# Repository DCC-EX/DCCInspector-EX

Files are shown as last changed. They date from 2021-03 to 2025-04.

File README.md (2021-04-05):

# DccInspector-EX

## Summary

Diagnostic/sniffer program for DCC analysis, based on an Arduino or ESP32 target.
The bit structure and packet structure are analysed and reported, and packets are decoded
and displayed in binary and also in a textual form.

On Arduino, the program produces output to the Serial port.  

On ESP32, it supports HTTP output via WiFi, and will display a reduced set of information
on an OLED display.  A button can be configured to allow the screen to be scrolled to display 
more information.  Development boards such as the Heltec Kit 32 include OLED and a button and
can be used directly.  The ESP32 will go into deep sleep mode (to preserve battery when used stand-alone) if no input 
DCC signal is detected for two minutes, it resumes when reset.

## Hardware Interface

The device may be directly connected to a DCC controller of the same I/O voltage and earth, e.g. in a
DCC++ or DCC++ EX system.  If it is used to monitor DCC signals, which are
normally bipolar 12-18V signals, an optocoupler circuit will be required.

Various circuits are discussed on the internet, but if you use a 6N137 optocoupler I 
would recommend a 1nF capacitor across the optocoupler input to stabilise the DCC input signal.  
Without this the opto-isolator may experience ringing, causing fleeting interrupts on the input 
(recorded as 'glitches' in the diagnostics).

I use a pull-up resistor of 470 ohms (labelled R3 below) on the output pin 6, connected to 5V; 
a larger resistor (even the Arduino's internal pull-up) will generally still work but may slow 
down the optocoupler.  Using the internal pull-up (~25Kohm), the rise-time on the signal is some microseconds 
in length, compared to around 200ns with a 470 (or 330) ohm pull-up.  This may be acceptable in a decoder where the
timing requirements may be relaxed, but a faster response is preferred for a diagnostic tool.

No connection is necessary to pin 7, although some versions of the circuit show a pull-up resistor here.

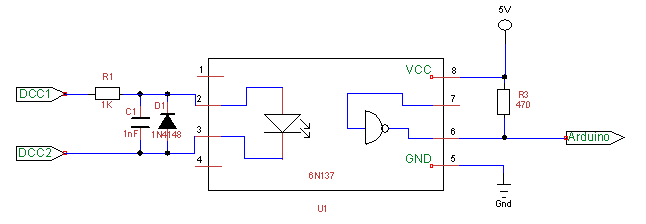
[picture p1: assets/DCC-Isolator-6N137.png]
Recommended Optocoupler Circuit


Strictly, the 6N137 isn't rated for the 3.3V supply used on an ESP8266 or ESP32.
I've had good results running with the circuit shown above with a 3.3V supply (replacing R3 with 330 ohm), 
but if you want to do things properly, the VCC terminal of the 6N137 should be
connected to +5V, or the optocoupler should be replaced with a 3.3V tolerant optocoupler.  In either case,
R3 should be connected to +3.3V to avoid putting too high a voltage on the ESP's input pin.

The default input pin used by the sketch depends on the target used.  For Arduino Uno and Nano, pin 8; 
for Mega, pin 49.  For the ESP8266/ESP32 it's GPIO2 (labelled D4 on the 8266 NodeMCU).

## Target Platforms

The diagnostic program supports the Arduino Uno, Nano, Mega and ESP32 particularly.

On Arduino, measurements are performed at an accuracy of 1/2 or 1/16th microsecond using Timer1 input 
capture mode, and calculation results are rounded to 1 microsecond.  

For increased compatibility with other microcontrollers, it is possible to use the micros() function for timing.
However, on an Arduino Uno/Nano/Mega this introduces up to 3us error in the micros() result, plus up to
6.5us uncertainty in the scheduling of the interrupt which samples the micros() value; consequently, the 
measured pulse length will, approximately once every millisecond, be off by up to 10us, and the rest of 
the time be up to 3us out.  This mode of operation is not recommended.

The sketch also supports the ESP8266 and ESP32.
On the ESP8266, the timing is performed using the micros() function.  Consequently, 
some inaccuracies due to interrupts are still present, of the order of 4us either way.  

The ESP32 runs in input capture mode, which works very well and potentially can support a 
measurement accuracy of around 4ns.  The sketch uses the default 12.5ns timer resolution and rounds 
the results to 1us accuracy.

## WiFi and Web Browser

On ESP8266 and ESP32, an HTTP server is provided which allows the output to be viewed from
a standard browser.  The first time the device starts, it will attempt to get WiFi credentials from the
router using WPS protocol.   Press the WPS button on the router before resetting the device, and
the device should connect to the router.  When the device is reset or started in future, it will 
connect using the same credentials by preference.

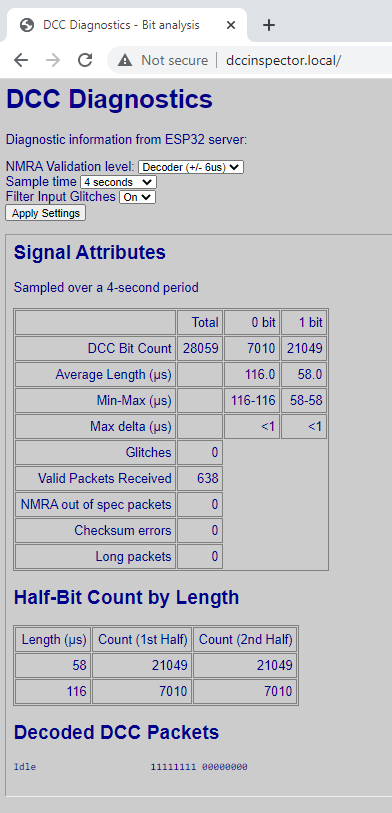
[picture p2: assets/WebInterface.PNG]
Example of output in web browser Example of web output


## Serial USB Output

The sketch produces output to the Serial stream, by default
once every 4 seconds.  The output statistics includes bit counts, 
bit lengths, checksum errors, packets too long, and 
time spent within the interrupt code.  Fleeting input state changes
(<= 3us) are optionally filtered and counted.  A break-down of pulse counts by 
length can also be produced, to monitor the consistency of the DCC signal.
The bit stream is validated against the specifications in NMRA S-9.1 (2020) for bit length 
and delta.  The validation can be selected through the serial monitor to be strict=0 (no validation), strict=1 
(NMRA Decoder compliance level) or strict=2 (NMRA Controller compliance level).  
The number of packets rejected due to non-compliance is recorded and displayed.

In between statistics output, received DCC packets are decoded and 
printed; duplicate throttle packets and idle packets are however not printed more than once per period.

Press '?' in the serial monitor to see help of the commands available.  The 
breakdown of pulse lengths is not displayed by default, press 'B' to enabled it.  
Likewise, the CPU statistics are not displayed by default, press 'C' to enable them.

## Example Output On Serial USB

### Example Uno Monitoring DCC++ EX 3.0.10 (5V, 6N137 Optocoupler, Main Track, Strict NMRA):
All DCC packets are within the NMRA specification
and the pulse lengths are always within 1us of the target lengths of 116us and 58us.

This demonstrates the improvements in pulse quality which were introduced in DCC++EX in 
version 3.0.5 when running on an ATmega2560 board with standard motor pins, compared to the pulse lengths
measured for the DCC++EX version 3.0.4 below.  It is achieved by using the Arduino's
hardware PWM capabilities to generate the pulse transitions; this is accurate to one clock cycle,
i.e. 1/16th of a microsecond, although the measurement accuracy is reduced slightly by the optocoupler circuit.

```
-
Bit Count/4 sec=25621 (Zeros=9134, Ones=16486), Glitches=0
Valid Packets=446, NMRA out of spec=0, Checksum Errors=0, Lost pkts=0, Long pkts=0
0 half-bit length (us): 115.9 (115-116) delta < 1
1 half-bit length (us): 57.9 (57-58) delta < 1
------ Half-bit count by length (us) -------
57	3218	0
58	13270	16490
115	2444	150
116	6690	8984
--------------------------------------------
--
Loc 3 Rev128 25         00000011 00111111 00011010
Loc 7979 Fwd128 122     11011111 00101011 00111111 11111011
-
```

### Example ESP32 Monitoring DCC++ EX 3.0.4 (5V, 6N137 Optocoupler, Main Track, Strict NMRA)
When the DCC signal is generated within interrupt handling code within the Command Station, the accuracy of 
the signal cannot be maintained to such a high accuracy.  Below, we can see that the pulse length varies over a range of around 14us.  
This would mean that some packets are outside of the NMRA specification and may be ignored by the loco decoder.
The analyser reports 81 packets as out of spec and 351 in-spec, i.e. around 20% are out of spec.  This is not 
normally a problem on a DCC layout as each packet is transmitted at least three times.  If one packet doesn't get 
through, the probability is that one of the retransmissions will!

The half-bit counts are turned off here, but CPU monitoring within the analyser is turned on.

```
-
Bit Count/4 sec=24865 (Zeros=10167, Ones=14697), Glitches=0
Valid Packets=351, NMRA out of spec=81, Checksum Errors=0, Lost pkts=0, Long pkts=0
0 half-bit length (us): 115.9 (109-122) delta < 14
1 half-bit length (us): 57.5 (51-64) delta < 14
IRC Duration (us): 2.2 (1-10),  CPU load: 27.5%
--
Loc 7552 Fwd128 33      11011101 10000000 00111111 10100010
Loc 3 Fwd128 25         00000011 00111111 10011010
-
```

### Example Uno Monitoring DCC++ Classic (5V direct connection, Main Track, Strict NMRA):
The original DCC++ Classic also uses the hardware PWM capabilities of the Arduino to generate the 
DCC pulse transitions.  This is capable of accuracy to within one clock cycle, as demonstrated in
the results below.

```
-
Bit Count/4 sec=27573 (Zeros=9881, Ones=17692), Glitches=0
Valid Packets=411, NMRA out of spec=0, Checksum Errors=0, Lost pkts=0, Long pkts=0
0 half-bit length (us): 100.0 (100-100) delta < 1
1 half-bit length (us): 58.0 (58-58) delta < 1
IRC Duration (us): 29.8 (27-39),  CPU load: 54.6%
------ Half-bit count by length (us) -------
58      17692   17692
100     9882    9882
--------------------------------------------
--
Loc 7801 Fwd128 55      11011110 01111001 00111111 10111000
Loc 2323 Fwd128 5       11001001 00010011 00111111 10000110
-
```

## Command Summary

Keyboard commands that can be sent via Serial Monitor:

```
 1 = 1s refresh time
 2 = 2s 
 3 = 4s (default)
 4 = 8s
 5 = 16s
 6 = 4 DCC packet buffer
 7 = 8
 8 = 16
 9 = 32 (default)
 0 = 64
 a = show accessory packets toggle
 l = show locomotive packets toggle
 d = show diagnostics toggle
 h = show heartbeat toggle
 b = show half-bit counts by length
 c = show cpu/irc usage in sniffer
 f = input filter toggle
 s = set NMRA compliance strictness (0=none,1=decoder,2=controller)
 ? = help (show this information)
```

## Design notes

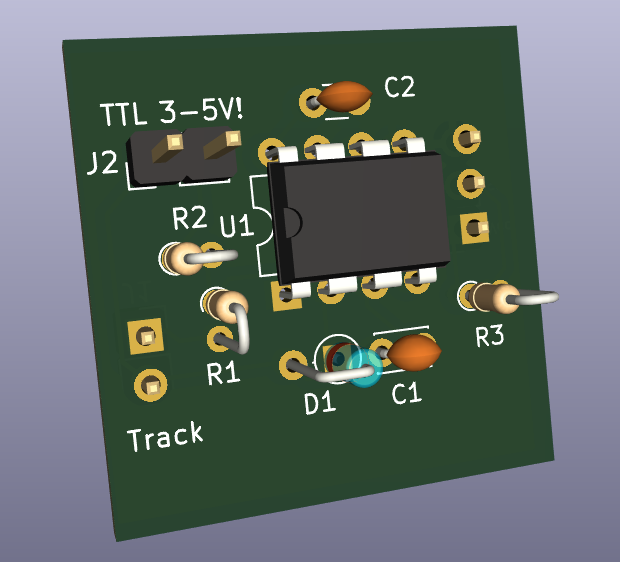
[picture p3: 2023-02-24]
hardware/optoiso-board-only/board_front.png

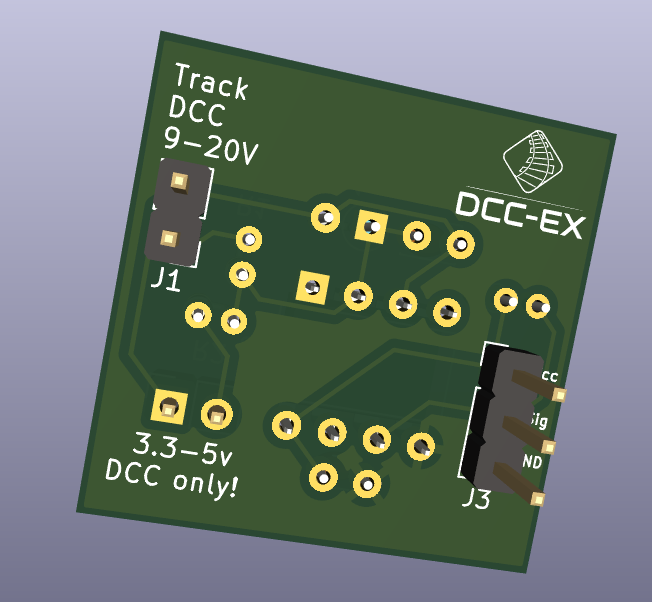
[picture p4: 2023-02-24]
hardware/optoiso-board-only/board_back.png

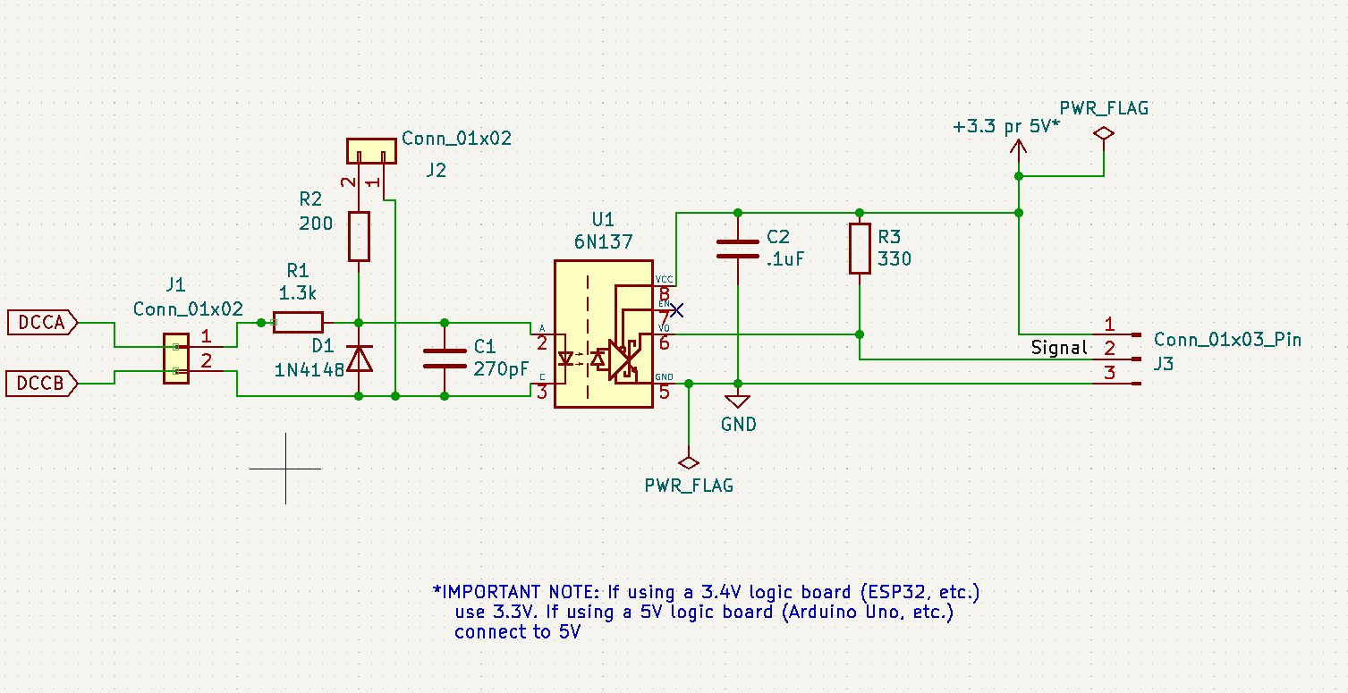
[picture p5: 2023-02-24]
hardware/optoiso-board-only/schematic.png

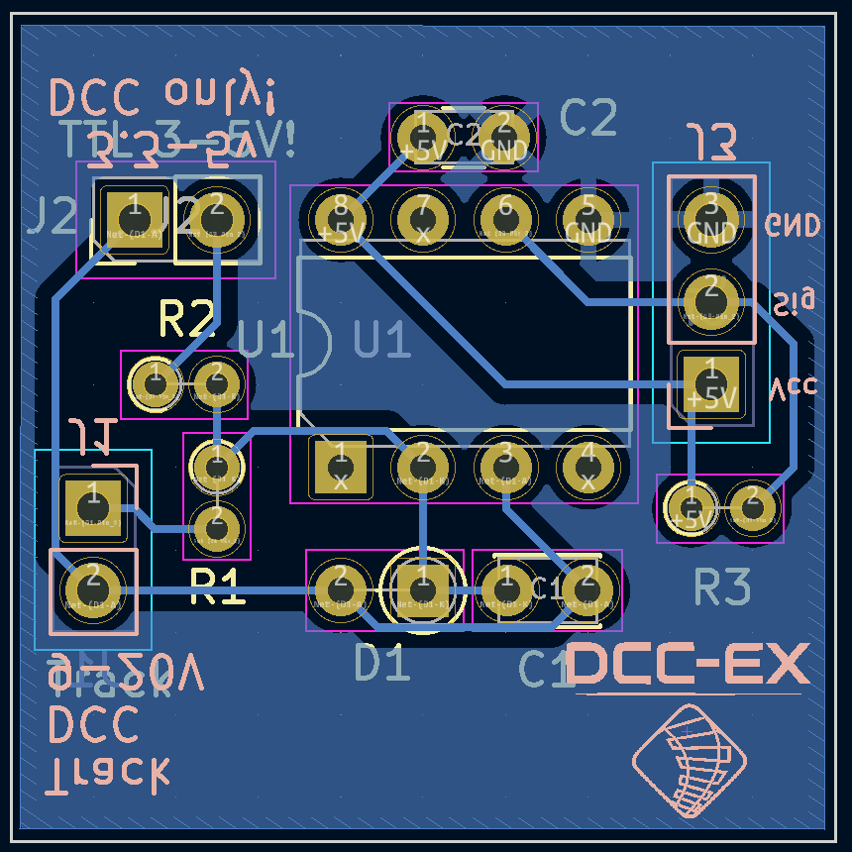
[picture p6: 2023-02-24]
hardware/optoiso-board-only/board_layout.png

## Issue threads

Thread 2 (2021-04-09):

High function numbers

Neil-McK, 2021-04-09:
Need to check for the handling of higher function numbers and add.

FrightRisk, 2021-04-19:
I left a note on Discord. Perhaps with the combination of the NMRA doc and the RCN-212 document it will be more clear. I hope this isn't another case of interpreting a spec 2 different ways.

Neil-McK, 2021-04-19:
Looks like the RCN again modifies DCC so full NMRA compliance means
non-compliance with RCN.

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

atanisoft, 2021-04-19:
RCN *DOES* add a few extended features to the DCC specifications through the usage of reserved bit patterns but otherwise is compliant from my last review. It can safely be used as a reference for NMRA compliance *IF* you exclude the extended packet formats that were added (they are noted IIRC). There is also an effort to synchronize the two as part of an updated NMRA standard. The latest revision of docs (even drafts) is available [here](https://github.com/nmradcc/documents).

Neil-McK, 2021-04-19:
Added decoding for function blocks 29 to 68.  Checked and corrected handling of binary state commands, both short form and long form.  Added in pull request #4.

Neil-McK, 2021-04-19:
Many of the problems I've encountered have been rooted in the
interpretation of the NMRA specification and the RCN specification.  A
specification is not a technical design, but many people expect the spec to
address every part of how to design equipment.  In fact the spec should be
limited to those aspects of a system that must be implemented in a
particular way in order to achieve desired performance, e.g. provide
interoperation with another system that is independently developed to the
same specification.  If something isn't specified, it's because it isn't an
aspect of the system that is critical to interoperation.  It should not be
assumed that, because something doesn't appear in the spec, it isn't
permitted.  If it says the decoder must accept '1' bit lengths up to 64us,
then it may also accept longer ones, unless the spec says it must reject
them.

Additions to a spec have to be made very carefully.  For example, the spec
may include definitions for functions 1-5 out of 6 possible values.  I can
later enhance the spec by defining function 6 behaviour.  Because function
6 was not previously specified, nothing is broken.  However, if I also
reallocate function 3 to do something else, I've broken the spec as any
equipment written to comply with the original spec will by necessity be
non-compliant with the new spec.

The particular aspect of the RCN that caused problems was the tightening of
the bit lengths for DCC '0' bits.  In the NMRA specs the '1' bit is tightly
specified, but a value '0' bit may be up to 1000us in half-bit length.  The
RCN spec reduces this to max 116us for a command station.

The nominal clock rate for DCC is somewhat problematic at 58/100us
half-cycle times as this requires changes to the clock rate as much as
every cycle.  DCC++EX uses 58/116us  half-cycle times as this allows a
regular 58us clock to generate the DCC signal- on some ticks the output
changes, some it doesn't.  This is easily NMRA compliant, but for RCN the
criterion is tighter.  Any command station that generates pulses longer
than 116us is NMRA compliant but not RCN compliant.  The RCN spec, in
comparison with the NMRA spec, is broken in this aspect.

There is also a discrepancy in the use of binary state commands.  The NMRA
spec, and the RCN spec too, specifies that binary states and functions are
similar in purpose but are not the same.  Therefore, system manufacturers
may use them freely.  Function 65 may perform a different operation to
binary state 65.  Conversely, the RCN spec states that function 65 and
binary state 65 must perform the same operation - another breaking change.

So that's two areas where the RCN differs from the NMRA specs in such a way
that equipment that is NMRA compliant may not be RCN compliant.

Hope this explains where I'm coming from, and my concerns with a second
standards body tweaking an existing spec for their own reasons.

Regards, Neil

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

atanisoft, 2021-04-19:
As noted the RCN specs/standards are being incorporated into the NMRA standards and are currently under review. Some aspects, like the bit timing, are likely to be revised along the way. It is an ongoing effort.

FrightRisk, 2021-04-21:
Who do we write to? Obviously there is at least one person at each organization who know each other and trade emails, how do we get in on the conversation?

atanisoft, 2021-04-21:
> Who do we write to?

You can try sending a message to @bakerstu who has been working with the NMRA DCC group for various revision activities.

FrightRisk, 2021-04-22:
@Neil-McK Do you know where you saw a max of 116 for pulse duration? This is my translation of RCN-210 from Dec 1, 2019
2.1 The "1" bit, one bit

- In a one-bit, the first and second halves must have a duration of **58 µs ± 3 µs**.
- The duration of a one-bit is therefore 116 µs ± 6 µs.
- Both halves of the bit must be of the same length with a tolerance of ± 3 µs.
- A decoder must accept a tolerance for a bit half of ± 6 µs.
- This means that a decoder must recognize such received bits as valid one-bits, both parts of which each have a duration between 52 µs and 64 µs.

2.2 The "0" bit, zero bit
- The nominal duration of both halves in a zero bit is 100 µs.
**- The minimum duration of half of a zero bit is 95 µs.
- The maximum duration of half of a zero bit is
   * 9900 µs if an analog locomotive should also be controlled.
   * 116 µs to maintain compatibility with other protocols and Protocol extensions.
- The total duration of a zero bit must not exceed 12000 µs.**
- In order to keep the DC components of the complete DCC track signal at zero as with the one bits, both parts of the zero bit
  are usually the same length.
- In order to obtain a DC voltage component for alternative control purposes, only one half of a zero bit may be extended.
- A decoder must recognize such received bits as valid zero bits, the first or second part of which has a duration between 90 µs and 10,000 µs.
All time measurements are related to the zero crossings, which are the middle between positive and negative signal amplitudes.
-------------------------------

So it depends how you read the section about 116µs.  Is this what you are talking about? It makes no sense to allow 95µs to 12000µs and then say any number in between is the limit. And if you argue that those values are only when controlling a DC loco, how do you know? Or would there be decoders, like accessory decoders, that could say, "I'm not controlling a loco, so I won't look at anything longer than 116µs"? But then it could not work on a mixed DC and DCC system.

atanisoft, 2021-04-22:
Here is one of the first NMRA DCC standards being updated with reference to RCN: https://www.nmra.org/sites/default/files/standards/sandrp/pdf/s-9.1_electrical_standards_for_digital_command_control_2021.pdf. This covers packet timing and track voltages primarily.

Neil-McK, 2021-04-22:
This hasn't significantly changed since the January revision, and
fortunately doesn't mention anything about the contentious 115us limit for
0 half-bits!

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

Neil-McK, 2021-04-22:
I don't understand why this discussion appears against this 'closed' change relating to function and binary state commands.  Or why it has been reopened.  Please clarify.

atanisoft, 2021-04-22:
> and happily still doesn't mention anything about the contentious 116us limit for 0 half-bits in the RCN spec!

Do you have a reference for that? The NMRA spec linked above is based off the old NMRA spec and RCN/NEM data incorporated.

Neil-McK, 2021-04-22:
See earlier message where Fred quotes from RCN-210 from Dec 1, 2019 section 2.2.

atanisoft, 2021-04-22:
> I can't see the 116us limit in the NMRA spec, the limits on half-bit length seem to remain as they were in the original NMRA specs.

Because that limit *DOESN'T* exist. The nominal is still 100usec for the half bit with a maximum total length for both halves being 12000usec. The most likely reason it is called out in the RCN spec is to provide a practical limit on the zero half bit time. This should have zero impact on DCC++EX for compliance with NMRA or RCN since DCC++EX is within the limits anyway.

Neil-McK, 2021-04-22:
Thank you, that is my whole point.  The RCN should not be the reference for
DCC, the NMRA specs should.  The differences in the RCN specs, for whatever
reason, just lead to confusion.

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

FrightRisk, 2021-04-22:
My mistake, I hit a button! Back to closed.

atanisoft, 2021-04-22:
RCN is intended as a clarification and extension on the NMRA standards. Some aspects are being integrated into the NMRA standards now with various WIP drafts.

FrightRisk, 2021-04-22:
And doesn't MOROP repeat the same basic specs?

atanisoft, 2021-04-22:
MOROP is related to RCN/NEM, it is mentioned in the draft I linked.

Closed 2021-04-22.

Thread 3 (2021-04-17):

Setting options through web interface

Neil-McK, 2021-04-17:
Currently, the options (NMRA validation particularly) can only be set through the serial interface.  It would be useful to be able to set this through a control on the web page.

FrightRisk, 2021-04-19:
Looks like you can check this one off ;)

Neil-McK, 2021-04-19:
I've spotted that the handling of long binary states is wrong, need to fix
that.  Away on holiday till Friday.

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

Neil-McK, 2021-04-19:
Options for NMRA level, sample period, and filter on/off added in pull request #4.

Closed 2021-04-19.

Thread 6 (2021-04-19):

Send IP Address to Serial Monitor on boot

FrightRisk, 2021-04-19:
I've never been able to get mDNS to work. I'm using an ESP-8285 and Chrome and can't find the device by name.  I needed to see the IP address since the ESP does not reset when you open the serial monitor like the Arduinos do and show startup info. Perhaps there is other status information that could be called here. In that case "i" could stand for "information" istead of "IP Address".

Closed 2021-04-19.

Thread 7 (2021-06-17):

Consistency with throttle commands in 28 and 128 speed step mode

FrightRisk, 2021-06-17:
In 128 speed step mode we list the command as "Fwd128", but in 28 speed step mode we call is "Forw". Should it be consistent? Either just "Fwd" or perhaps better as "Fwd28". What do you think?

### Short Address 128 Speed Steps

```
Loc 3 Fwd128 40         00000011 00111111 10101001
Loc 3 Fwd128 Stop       00000011 00111111 10000000
```

### Short Address 28 Speed Steps <D SPEED28>

```
Loc 3 Forw 12           00000011 01110111
Loc 3 Stop              00000011 01100000
```

Neil-McK, 2021-06-20:
Modified in Pull Request #8.

Neil-McK, 2023-03-09:
Fix was added to main branch in 2021 so issue closed.

Closed 2023-03-09.

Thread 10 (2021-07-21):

Multiple Predefined WiFi networks in config.h

twr140, 2021-07-21:
This is a suggestion for a new feature / improvement.

Would it be possible to amend the stand alone unit, running on an ESP32, to use the multiWiFi library, so that it can connect to whichever one of several predefined WiFi networks is available at the time?

This would be useful when the device is moved from home, to a club layout, then to a demonstration layout etc.

Certainly in my case, WPS is not an option for the club and demonstration layouts, so if I don't reprogram the device before leaving home, it can't be accessed from the network and the web page is therefore unavailable.

This would require adding the SSID and password for each desired network into the config.  If the device can't connect to the last WiFi network on startup, and can't connect via WPS, then it could try connecting to whichever of the preset networks are available.

Thanks for considering this suggestion.

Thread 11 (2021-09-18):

DIO2.h needs to be installed manually

akaeba, 2021-09-18:
Hi Neil,

if i use Arduino 1.8.16 then is the Lib DIO2.h not autoamtically resolved. I need to install manually via Library Manager. Is there an way in Arduino to add this Lib as item to be automatic resolved?

Thanks in advance and for distributing such a nice Project!

Best Regards
Andreas

Neil-McK, 2023-03-09:
Hi Andreas,

Unfortunately the Arduino IDE doesn't allow automatic installation of missing libraries.  However, you might want to take a look at the PlatformIO IDE - it is much more functional and informative than the Arduino IDE and it uses the file `platformio.ini` which contains library references and board types; so everything needed is installed automatically when needed.  You don't need to look at Boards Manager or Library Manager, it's done for you.    https://platformio.org/

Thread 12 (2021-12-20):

Compile errors using esp32 Board library 2.0.0 and 2.0.1, in Arduino IDE 1.8.6

twr140, 2021-12-20:
If either of the above board libraries are used, this sketch fails to compile (in the Arduino IDE), with the final error message shown as:
```
'struct esp_wps_config_t' has no member named 'crypto_funcs'
```
I first noticed this when I had v2.0.1 of the board library installed.  Taking this library back to v2.0.0 did not resolve the problem - the error message remained the same.

When I went back to v1.0.6 of the library, this error disappeared.

Here is the full text of the compiler error when v2.0.0 of the library was in use:
```
Arduino: 1.8.16 (Windows 10), Board: "Heltec WiFi Kit 32, Disabled, 240MHz (WiFi/BT), 921600, None"

C:\Users\abc\Documents\Arduino\DCCInspector-EX\HttpManager.cpp: In member function 'bool HttpManagerClass::begin(const char*, const char*, const char*)':

HttpManager.cpp:187:10: error: 'struct esp_wps_config_t' has no member named 'crypto_funcs'

   config.crypto_funcs = &g_wifi_default_wps_crypto_funcs;

          ^~~~~~~~~~~~

HttpManager.cpp:187:26: error: 'g_wifi_default_wps_crypto_funcs' was not declared in this scope

   config.crypto_funcs = &g_wifi_default_wps_crypto_funcs;

                          ^~~~~~~~~~~~~~~~~~~~~~~~~~~~~~~

HttpManager.cpp:190:26: error: no matching function for call to 'onEvent(void (&)(arduino_event_id_t, system_event_info_t))'

   WiFi.onEvent (WiFiEvent);

                          ^

In file included from C:\Users\abc\AppData\Local\Arduino15\packages\esp32\hardware\esp32\2.0.0\libraries\WiFi\src/WiFiSTA.h:28,

                 from C:\Users\abc\AppData\Local\Arduino15\packages\esp32\hardware\esp32\2.0.0\libraries\WiFi\src/WiFi.h:32,

                 from C:\Users\abc\Documents\Arduino\DCCInspector-EX\HttpManager.h:37,

                 from C:\Users\abc\Documents\Arduino\DCCInspector-EX\HttpManager.cpp:33:

C:\Users\abc\AppData\Local\Arduino15\packages\esp32\hardware\esp32\2.0.0\libraries\WiFi\src/WiFiGeneric.h:147:21: note: candidate: 'wifi_event_id_t WiFiGenericClass::onEvent(WiFiEventCb, arduino_event_id_t)' <near match>

     wifi_event_id_t onEvent(WiFiEventCb cbEvent, arduino_event_id_t event = ARDUINO_EVENT_MAX);

                     ^~~~~~~

C:\Users\abc\AppData\Local\Arduino15\packages\esp32\hardware\esp32\2.0.0\libraries\WiFi\src/WiFiGeneric.h:147:21: note:   conversion of argument 1 would be ill-formed:

HttpManager.cpp:190:26: error: invalid conversion from 'void (*)(arduino_event_id_t, system_event_info_t)' to 'WiFiEventCb' {aka 'void (*)(arduino_event_id_t)'} [-fpermissive]

   WiFi.onEvent (WiFiEvent);

                          ^

In file included from C:\Users\abc\AppData\Local\Arduino15\packages\esp32\hardware\esp32\2.0.0\libraries\WiFi\src/WiFiSTA.h:28,

                 from C:\Users\abc\AppData\Local\Arduino15\packages\esp32\hardware\esp32\2.0.0\libraries\WiFi\src/WiFi.h:32,

                 from C:\Users\abc\Documents\Arduino\DCCInspector-EX\HttpManager.h:37,

                 from C:\Users\abc\Documents\Arduino\DCCInspector-EX\HttpManager.cpp:33:

C:\Users\abc\AppData\Local\Arduino15\packages\esp32\hardware\esp32\2.0.0\libraries\WiFi\src/WiFiGeneric.h:149:21: note: candidate: 'wifi_event_id_t WiFiGenericClass::onEvent(WiFiEventSysCb, arduino_event_id_t)' <near match>

     wifi_event_id_t onEvent(WiFiEventSysCb cbEvent, arduino_event_id_t event = ARDUINO_EVENT_MAX);

                     ^~~~~~~

C:\Users\abc\AppData\Local\Arduino15\packages\esp32\hardware\esp32\2.0.0\libraries\WiFi\src/WiFiGeneric.h:149:21: note:   conversion of argument 1 would be ill-formed:

HttpManager.cpp:190:26: error: invalid conversion from 'void (*)(arduino_event_id_t, system_event_info_t)' to 'WiFiEventSysCb' {aka 'void (*)(arduino_event_t*)'} [-fpermissive]

   WiFi.onEvent (WiFiEvent);

                          ^

Multiple libraries were found for "WiFi.h"

 Used: C:\Users\abc\AppData\Local\Arduino15\packages\esp32\hardware\esp32\2.0.0\libraries\WiFi

 Not used: C:\Program Files (x86)\Arduino\libraries\WiFi

exit status 1

'struct esp_wps_config_t' has no member named 'crypto_funcs'
```

Neil-McK, 2023-03-07:
The code reported as in error has been modified and compiled without errors and ran with ESP32 support v2.0.4 (most recent version on PlatformIO and on Arduino IDE).  Thanks for reporting this, and sorry it's been so long.

twr140, 2023-03-08:
Thanks for looking into this Neil.

I'm now running the Arduino IDE 2.0.4, and I upgraded the ESP32 library today to v2.0.7.  I then downloaded the DCCInspector-EX code as a ZIP file and placed the new code in the Arduino folder on my system.  I've set the board to the Heltec WiFi Kit 32.  When I try to compile it, I'm now getting a different error:

`Compilation error: expected unqualified-id before numeric constant`

Here is the full error text:

`In file included from C:\Users\Trevor\Documents\Arduino\DCCInspector-EX\OledDisplay.cpp:24:
C:\Users\Trevor\Documents\Arduino\DCCInspector-EX\Config.h:101:20: error: expected unqualified-id before numeric constant
   #define SCL_OLED 5
                    ^
C:\Users\Trevor\AppData\Local\Arduino15\packages\esp32\hardware\esp32\2.0.7\variants\heltec_wifi_kit_32/pins_arduino.h:72:22: note: in expansion of macro 'SCL_OLED'
 static const uint8_t SCL_OLED = 15;
                      ^~~~~~~~
C:\Users\Trevor\Documents\Arduino\DCCInspector-EX\Config.h:100:20: error: expected unqualified-id before numeric constant
   #define SDA_OLED 4
                    ^
C:\Users\Trevor\AppData\Local\Arduino15\packages\esp32\hardware\esp32\2.0.7\variants\heltec_wifi_kit_32/pins_arduino.h:73:22: note: in expansion of macro 'SDA_OLED'
 static const uint8_t SDA_OLED = 4;
                      ^~~~~~~~

exit status 1

Compilation error: expected unqualified-id before numeric constant`

I assume I've got something wrong on my system.  Can you assist please?

FrightRisk, 2023-03-08:
Did you clear everything out of the folder first? What version of the Adafruit SSD1306 Library do you have installed? Strange that I was able to duplicate that error, which is an odd error, but when something I did made that disappear and others appear. I was bouncing back and forth between the 1.8.9 IDE and the 2.0.4 IDE and I installed the latest Adafruit library. Now I get different errors.

Neil-McK, 2023-03-08:
Sorry, I was a bit premature in my comments here - I've produced a new version in the bugfixes branch, but that hasn't made its way to master yet.  I should have made that clear.  The latest error you are seeing appears to come from the order in which the include files are included, I'll look at fixing that too.

Neil-McK, 2023-03-08:
The problem is that there used to be a `#define ARDUINO_HELTEC_WIFI_KIT_32` implicit during the compilation, but that appears to have disappeared in the more recent versions of the ESP32 support.  So the only platform test that can be done in this version of the Arduino IDE is `#ifdef ESP_PLATFORM' which covers lots of boards and processors.  I've moved the #includes around so that the compilation error no longer happens, but you will need to edit the `Config.h` to reflect the board configuration, e.g. by adding an explicit `#define ARDUINO_HELTEC_WIFI_KIT_32` to the top of `Config.h`.  Once I've put the bugfixes into the master branch I'll update the comment and close this issue.

atanisoft, 2023-03-08:
> The problem is that there used to be a `#define ARDUINO_HELTEC_WIFI_KIT_32` implicit during the compilation, but that appears to have disappeared in the more recent versions of the ESP32 support.
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
Neil-McK, 2023-03-08:
When using PlatformIO, the macro ARDUINO_HELTEC_WIFI_KIT_32 is being defined and not ARDUINO_heltect_wifi_kit_32, so the conditional compilation works as intended.

Neil-McK, 2023-03-08:
The original Heltec esp32 platform has the following in the boards.txt in the Arduino15 folder:  `wifi_kit_32.build.board=WIFI_KIT_32`
The corresponding entry in the esp32 2.0.7 platform is:
`heltec_wifi_kit_32.build.board=heltec_wifi_kit_32`
Looking through the boards.txt, there isn't much consistency about capitalisation of the board names.  Many are upper case but some are mixed case and a few lower case.

PlatformIO doesn't appear to have a `boards.txt` but it does have files like `heltec_wifi_kit_32.json` which contains:
```
{
  "build": {
    "arduino":{
      "ldscript": "esp32_out.ld"
    },
    "core": "esp32",
    "extra_flags": "-DARDUINO_HELTEC_WIFI_KIT_32",
    "f_cpu": "240000000L",
    "f_flash": "40000000L",
    "flash_mode": "dio",
    "mcu": "esp32",
    "variant": "heltec_wifi_kit_32"
  },
  "connectivity": [
    "wifi",
    "bluetooth",
    "ethernet",
    "can"
  ],
  "frameworks": [
    "arduino",
    "espidf"
  ],
  "name": "Heltec WiFi Kit 32",
  "upload": {
    "flash_size": "4MB",
    "maximum_ram_size": 327680,
    "maximum_size": 4194304,
    "require_upload_port": true,
    "speed": 460800
  },
  "url": "http://www.heltec.cn/project/wifi-kit-32/?lang=en",
  "vendor": "Heltec Automation"
}
```

atanisoft, 2023-03-08:
> there isn't much consistency about capitalisation of the board names.

An issue should definitely be logged as it should always be upper case to be consistent with typical usages / recommendations for #define based constants.

atanisoft, 2023-03-08:
Accidentally hit the close button, sorry...

twr140, 2023-03-08:
Well I certainly didn't expect to wake up to all this!

> Sorry, I was a bit premature in my comments here - I've produced a new version in the bugfixes branch, but that hasn't made its way to master yet. I should have made that clear. The latest error you are seeing appears to come from the order in which the include files are included, I'll look at fixing that too.

@Neil-McK: I'm sorry if I was too quick to try this out and have caused problems.

@FrightRisk:

> Did you clear everything out of the folder first? What version of the Adafruit SSD1306 Library do you have installed? Strange that I was able to duplicate that error, which is an odd error, but when something I did made that disappear and others appear. I was bouncing back and forth between the 1.8.9 IDE and the 2.0.4 IDE and I installed the latest Adafruit library. Now I get different errors.

Reading through all the rest of the comments since you asked this, I think this isn't relevant, but my Adafruit SSD1306 library is v2.5.7

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

Thanks, but I won't bother yet.  I simply tested this yesterday because Neil had kindly posted what I thought was a fix to the issue I raised, and felt it was the right thing to do to try it out and provide feedback.

Thanks everyone for investigating this.  Sorry that I can't help, but I'm not a programmer.  I only know enough to be able to cobble together simple code for my own stuff, and most of the time just use what others such as yourselves kindly provide.

Neil-McK, 2023-03-09:
Not at all, thanks for the feedback.  You can see that it was very useful to us!  I'll try to be more explicit on the state-of-play in future, to avoid raising expectations.

Neil-McK, 2023-03-23:
The relevant changes have now been applied in the `master` branch, please confirm if the problem has been solved.

twr140, 2023-03-23:
Thanks @Neil-McK
I have successfully compiled the code this morning.  From my quick check, it all seems to be working on the actual hardware as well.

There does appear to be an issue with the new(?) battery voltage check in setup() though.  I'll open another Issue for it because it isn't related to this issue.

Neil-McK, 2023-03-24:
Thanks for the update.  I was aware that the esp32 battery check isn't
quite right. It was something I had on an esp8266 which worked fine.  The
heltec esp32 should have the same connections but I don't know why it
doesn't work.

Cheers!

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

Closed 2023-03-08.

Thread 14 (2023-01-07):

HW input capture not working on Mega 2560, fix proposed.

cpm64, 2023-01-07:
### EX-DCCInspector Version

Latest cf6a374

### Bug description

Using HW input capture mode is not working on Arduino Mega 2560 pin D49 due to a wrong macro test.

Sketch
On ArduinOMega 2450When #define USETIMER is defined in Config.h

### Steps to reproduce the bug

1. #define USETIMER
2. Connect the DCC interface to D49
3. Compile and upload the sketch
4. Open a serial console
```
[16:45:08:562] DCC Packet Analyze initialising
[16:45:08:566] INPUTPIN=49
[16:45:08:566]
[16:45:08:566] ** WARNING Measurements will occasionally be out up to ~10us either way **
[16:45:08:574] **         because of inaccuracies in the micros() function.            **
[16:45:08:578] Calibrating... done.
[16:45:09:573] ERROR: Pin 49 has no interrupt support
[16:45:09:578] Unable to start EventTimer, check configured pin

```

### Expected behaviour

Normal operation on pin D49

### Screenshots

_No response_

### Hardware in use

Adruino Mega 2560

### Additional context

**The issue** comes from EventTimer.h @ line 26 where ARDUINO_AVR_MEGA was not defined (possible a typo).

`#if defined(ARDUINO_UNO_NANO) || defined(ARDUINO_AVR_MEGA)`

The define is done in 'Config.h' @ line 30-31
`#elif defined(ARDUINO_AVR_MEGA2560)
  #define ARDUINO_MEGA
`

**Fix:**
In EventTimer.h change line 26 into:
`#if defined(ARDUINO_UNO_NANO) || defined(ARDUINO_MEGA)`

After uploading the new FW, the pin D49 can be used for DCC:
```
[16:53:46:965] DCC Packet Analyze initialising
[16:53:46:969] INPUTPIN=49
[16:53:46:969] Calibrating... done.
[16:53:47:964] Updates every 4 seconds
[16:53:47:964] ---
[16:53:47:976] Loc 1 L F4-F1 0         00000001 10000000
[16:53:47:989] Loc 2 L F4-F1 10000     00000010 10010000
[16:53:47:992] Loc 3 L F4-F1 10000     00000011 10010000
```

Neil-McK, 2023-03-07:
EventTimer.h updated to `#if defined(ARDUINO_UNO_NANO) || defined(ARDUINO_AVR_MEGA2560)` and tested.

Neil-McK, 2023-03-09:
Note - the fix is initially in the bugfixes branch and will be move to main branch shortly.

Neil-McK, 2023-03-23:
Fix has been applied in the `master` branch, so suggest closing it.

Closed 2024-03-12.

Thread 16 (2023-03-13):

[Support Request]:

uli-2016, 2023-03-13:
### Version

Current v´Version

### Issue description

I am using an ESP8266 D1 mini. When the DCC signal is applied to GPIO2 / D4, the ESP does not boot. Is another PIN better suited ?

thanks

### Hardware

ESP8266 D1 mini

Neil-McK, 2023-03-23:
Incidentally, I believe the recommended opto-isolator circuit uses a pull-up, so will be high state if the opto is off.  So if the device isn't connected to the track when you power on the D1 Mini, the input should be High, and D4 should work fine.  You can then connect the device to the track.   A more elaborate solution would be to use the enable input of the 2N617 opto to ensure that the input to the D1 Mini is kept pulled up until the controller has booted.

uli-2016, 2023-03-26:
Hi Neil,

GPIO2 on ESP8266 is the Pin D4. I did some research and found this documentary. I have
#define INPUTPIN 12  # D6 / GPIO 12        and it seems to work.

https://randomnerdtutorials.com/esp8266-pinout-reference-gpios/

Thanks

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

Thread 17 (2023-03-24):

Battery Voltage reported as "Battery Low" on Heltec WiFi Kit32

twr140, 2023-03-24:
### EX-DCCInspector Version

Version posted to fix issue #12

### Bug description

On my hardware, I have a 14500 Lipo battery powering the Heltec WiFi Kit32 module.

With a freshly charged battery (measured at 4.04V while powering the ESP32 system), the new code displays "Battery Low" when the device is turned on.

After this, the system seems to operate correctly

### Steps to reproduce the bug

Connect 14500 Lipo battery to Battery In connector on Heltec WiFi Kit32

Display shows "Battery Low" as the first line on the display.

Battery Voltage measured to be 4.04V

### Expected behaviour

The "Battery Low" message should not be displayed

### Screenshots

_No response_

### Hardware in use

Heltec WiFi Kit32

### Additional context

_No response_

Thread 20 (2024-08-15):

Bug Report: ESP32 S does not work

Jvsjvs, 2024-08-15:
### EX-DCCInspector Version

9.1.0

### Bug description

I have a board with an ESP32 **S** on it.

I use this board to decode DCC signals which works perfectly (on GPIO 4). So I know that the board works and that the DCC interface works. The board is connected to the track and currently controlling  turnouts.

If I download your firmware to this board and configure it to use GPIO4 it does not work:
- Http server starts and hosts the website
- It shows zero activity on the DCC bus while the board is connected to a valid DCC signal.

If I flash my own SW the board again functions perfectly, decodes DCC and controls the connected turnouts.

Any idea what could go wrong, I guess it has to do with the "S" version of the ESP32.

### Steps to reproduce the bug

Run the software on a board with an ESP32 **S**

### Expected behaviour

Activity on the DCC track should be detected, it currently detects nothing.

### Screenshots

_No response_

### Hardware in use

ESP32S populated board (own design)

### Additional context

_No response_

habazut, 2024-08-15:
What version of inspector
What version of ESP32 framework
Do you not get any capture interrupts at all or are all packets discarded with wrong times?
Do a print just to be sure you got the right input pin (default is GPIO5).

Harald.

habazut, 2024-08-15:
The ESP32 uses the mcpwm capture mechanism which should be the same on the ESP32-S3, but who knows with espressif? Does setting the IDF debug level to max verbose give any more information?
No, I don't have any more ideas and I don't have any S3.
Harald.

Jvsjvs, 2024-08-21:
Problem solved. The SW works as is on an EPS32S.

My own SW was a bit more tolerant to the input signal. I changed the input filter on my board a bit and now the Inspector also works on my board.

Thanks.

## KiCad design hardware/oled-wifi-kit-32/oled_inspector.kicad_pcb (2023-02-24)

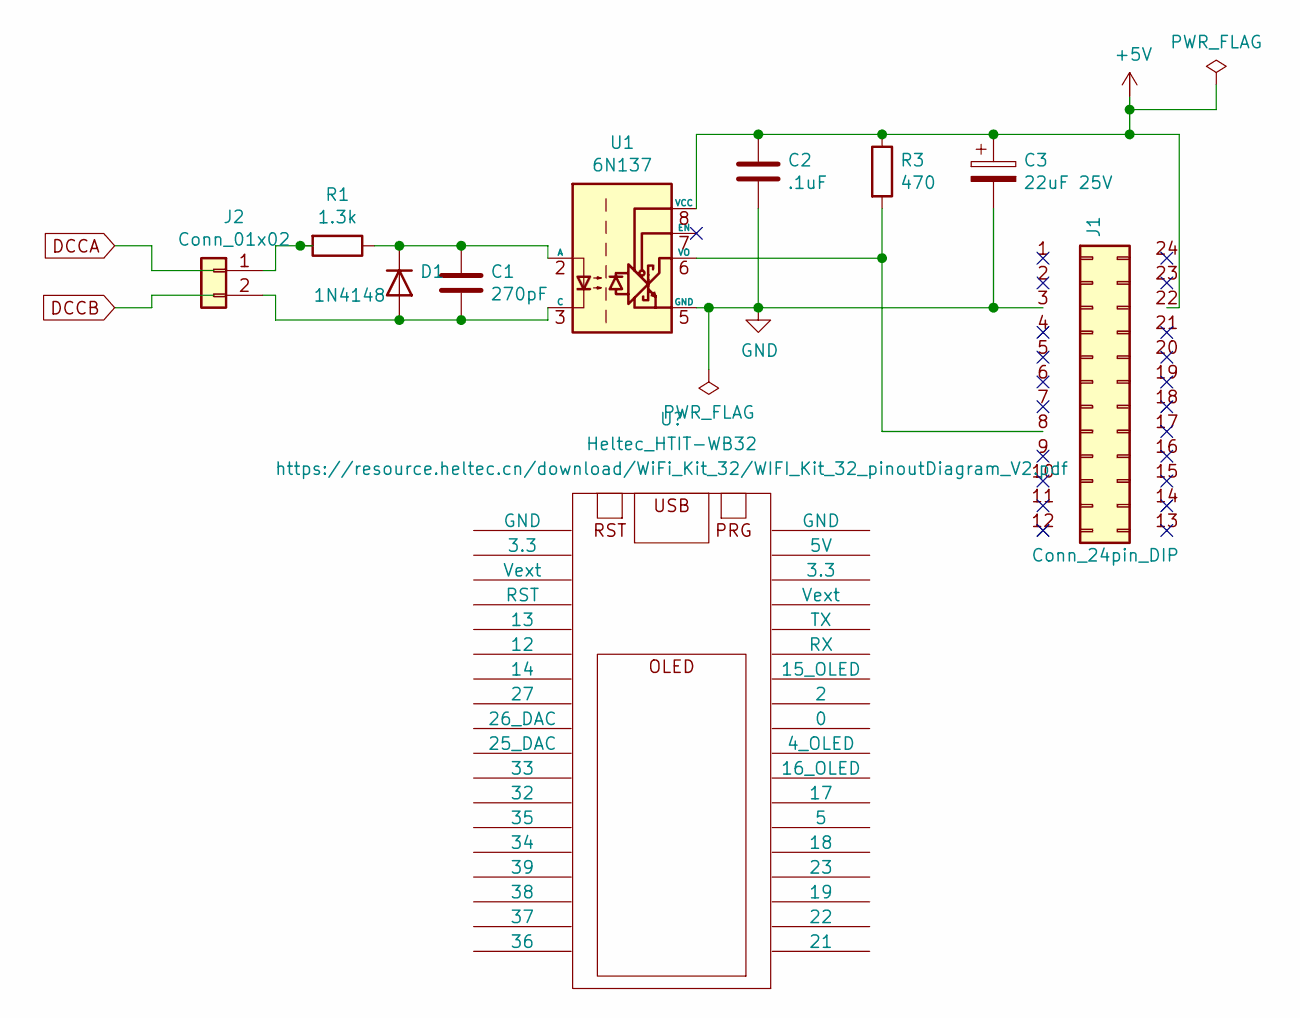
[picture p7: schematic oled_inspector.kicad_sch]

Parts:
C1: 270pF; CP_Radial_D8.0mm_P5.00mm
C2: .1uF; C_Disc_D3.0mm_W1.6mm_P2.50mm
C3: 22uF 25V; CP_Radial_D5.0mm_P2.00mm
D1: 1N4148; D_DO-35_SOD27_P7.62mm_Horizontal
J1: Conn_24pin_DIP; DIP-24_W15.24mm_Socket
J2: Conn_01x02; PinHeader_1x02_P2.54mm_Vertical
R1: 1.3k; R_Axial_DIN0204_L3.6mm_D1.6mm_P1.90mm_Vertical
R3: 470; R_Axial_DIN0204_L3.6mm_D1.6mm_P1.90mm_Vertical
U1: 6N137; DIP-8_W7.62mm

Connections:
+5V: C2.1, C3.1, J1.22, R3.1, U1.8 (VCC)
GND: C2.2, C3.2, J1.3, U1.5 (GND)
unnamed: C1.1, D1.1 (K), R1.1, U1.2 (A)
unnamed: C1.2, D1.2 (A), J2.2, U1.3 (C)
unnamed: J1.8, R3.2, U1.6 (VO)
unnamed: J2.1, R1.2

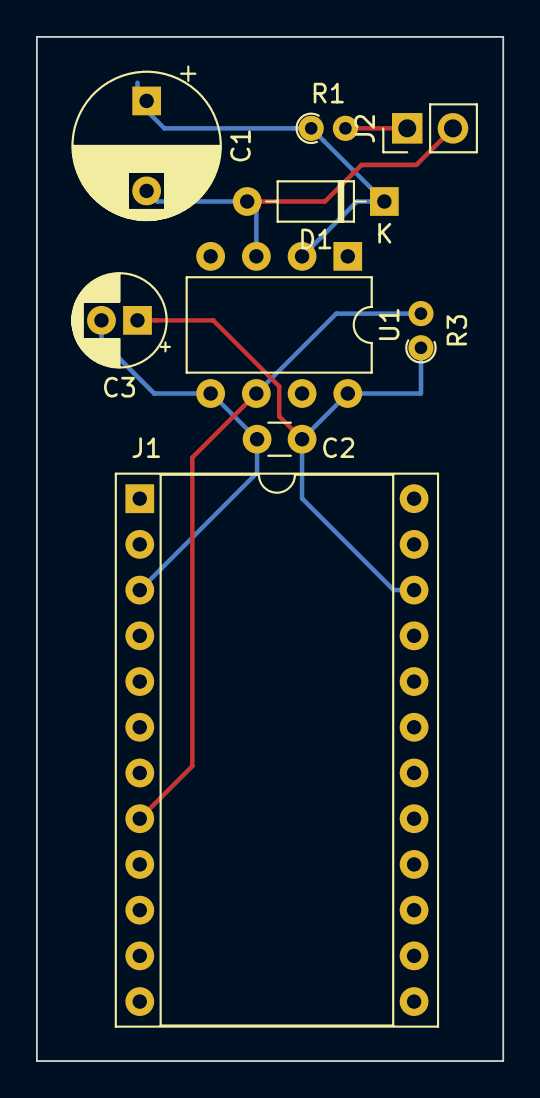
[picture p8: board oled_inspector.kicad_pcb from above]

Board: 2 copper layers, 25.9 x 56.9 mm, 9 parts (0 on the bottom side), 6 nets.

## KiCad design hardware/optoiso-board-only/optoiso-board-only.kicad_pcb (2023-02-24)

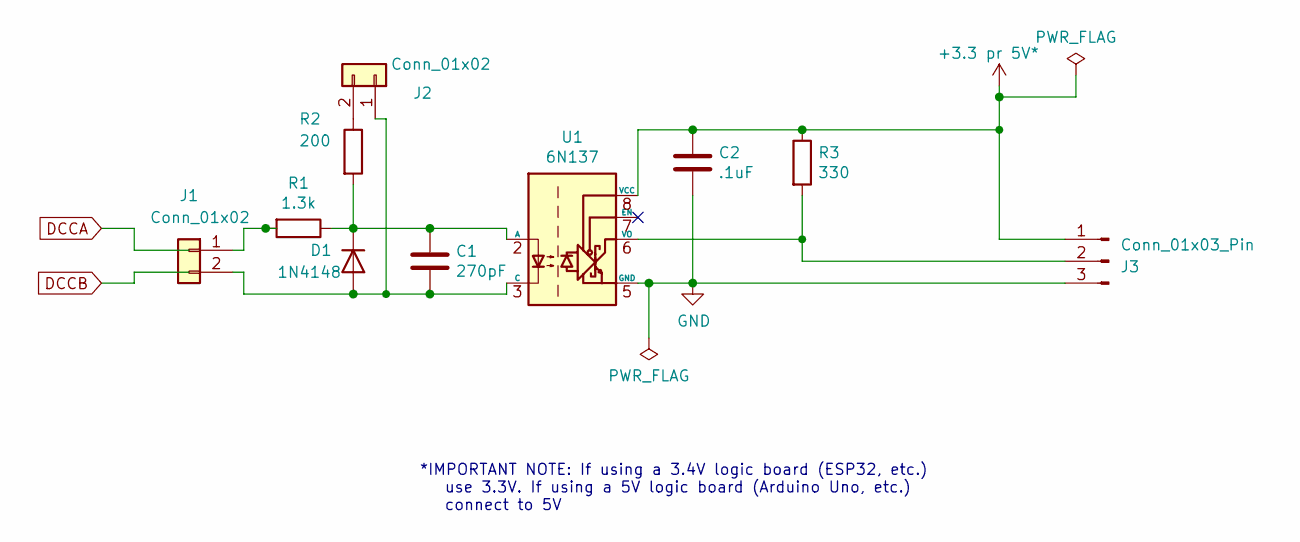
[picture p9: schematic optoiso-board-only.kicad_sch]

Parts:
C1: 270pF; C_Disc_D3.0mm_W2.0mm_P2.50mm
C2: .1uF; C_Disc_D3.0mm_W1.6mm_P2.50mm
D1: 1N4148; D_DO-35_SOD27_P2.54mm_Vertical_AnodeUp
J1, J2: Conn_01x02; PinHeader_1x02_P2.54mm_Vertical
J3: Conn_01x03_Pin; PinHeader_1x03_P2.54mm_Vertical
R1: 1.3k; R_Axial_DIN0204_L3.6mm_D1.6mm_P1.90mm_Vertical
R2: 200; R_Axial_DIN0204_L3.6mm_D1.6mm_P1.90mm_Vertical
R3: 330; R_Axial_DIN0204_L3.6mm_D1.6mm_P1.90mm_Vertical
U1: 6N137; DIP-8_W7.62mm

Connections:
+5V: C2.1, J3.1, R3.1, U1.8 (VCC)
GND: C2.2, J3.3, U1.5 (GND)
unnamed: C1.2, D1.2 (A), J1.2, J2.1, U1.3 (C)
unnamed: C1.1, D1.1 (K), R1.1, R2.2, U1.2 (A)
unnamed: J1.1, R1.2
unnamed: J2.2, R2.1
unnamed: J3.2, R3.2, U1.6 (VO)

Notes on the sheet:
*IMPORTANT NOTE: If using a 3.4V logic board (ESP32, etc.) use 3.3V. If using a 5V logic board (Arduino Uno, etc.) connect to 5V

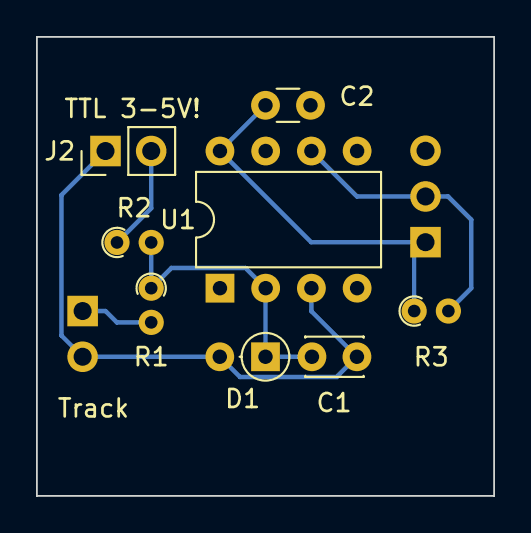
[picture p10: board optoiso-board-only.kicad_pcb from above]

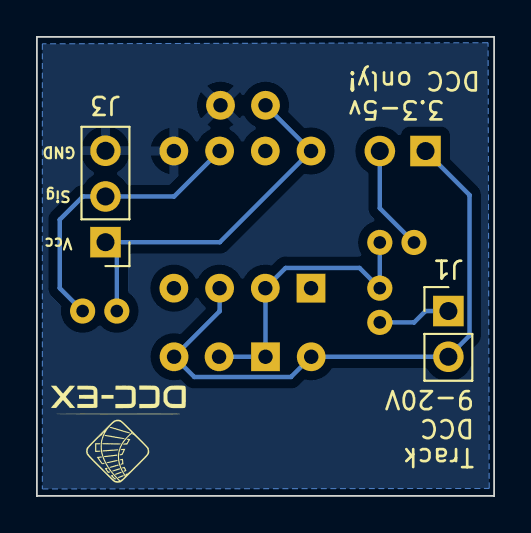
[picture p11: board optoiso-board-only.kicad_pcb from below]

Board: 2 copper layers, 25.4 x 25.5 mm, 10 parts (2 on the bottom side), 7 nets.

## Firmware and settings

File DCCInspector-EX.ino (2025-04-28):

/* Copyright (c) 2021 Neil McKechnie
 * Parts based on DCC_Sniffer, Ruud Boer, October 2015
 *
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
 * You should have received a copy of the GNU General Public License
 * along with this software.  If not, see
 * <http://www.gnu.org/licenses/>.
 */

///////////////////////////////////////////////////////
//
// Add buttons to web page for modifying options: NMcK Apr 2021
// Regroup functions into separate classes: NMcK Jan 2021
// Move configuration items to Config.h: NMcK Jan 2021
// Add OLED, and web server support on ESP32: NMcK Jan 2021
// Add capture for ESP32; refactor timers: NMcK Jan 2021
// Improve accuracy of timing and time calculations: NMcK Jan 2021
// Add support for compilation for ESP8266 and ESP32: NMcK Jan 2021
// Use ICR for pulse measurements, and display pulse length histogram: NMcK Dec 2020
// Add CPU load figures for the controller: NMcK December 2020
// Count, and optionally filter, edge noise from input: NMcK December 2020
// Display half-bit lengths rather than bit lengths: NMcK December 2020
// Improved comments; moved some strings to flash: NMcK November 2020
// Moved frame construction into interrupt code: NMcK July 2020
// Removed use of AVR timer interrupts: NMcK June 2020
// DCC packet analyze: Ruud Boer, October 2015
//
// The DCC signal is detected on Arduino digital pin 8 (ICP1 on Uno/Nano),
// or pin 49 (ICP4 on Mega), or pin GPIO2 on ESP8266/ESP32.  This causes an interrupt,
// and in the interrupt response code the time between interrupts is measured.
//
// Use an opto-isolator between the track signal (~30V p-p) and the
// digital input (0 to 5V or 0 to 3.3V) to prevent burn-out.
//
// Written originally for Uno but also tested on Mega and Nano,
// should work on other architectures if simple options chosen (no USETIMER and
// no USE_DIO2).
//
// Also tested on ESP8266 (NodeMCU and Heltec Kit 8) and ESP32 (Heltec Kit 32).  Both of these
// support OLED display and HTTP server on WiFi.  See Config.h for configuration options.
// It will decode bits on the input pin which is GPIO2 for ESP8266 (labelled D4 on the NodeMCU) or 
// GPIO5 on the ESP32.
//
// The faster clock speeds on the ESP8266/ESP32 mean that interrupt jitter is less, but there is 
// still around +/- 4us evident on the ESP8266.  Also, the ESP8266 and ESP32, micros() does
// actually give a resolution of 1 microsecond (as opposed to 4us on the Arduino).  The ESP32
// gives the best performance and functionality, with its input capture capability alongside the 
// OLED/Wifi.
//
// The use of ICPn on the Arduino and ESP32 enables accurate timing to within 1us.  The millis() 
// function in the Arduino is no better than 10.5us or so accurate (6.5us interrupt jitter caused by the
// Arduino Timer0 interrupts, and 4us timer resolution) which is inadequate for diagnostic purposes.
//
// The selected digital input must have interrupt support, either via
// the level change interrupt (e.g. Arduino pin 2 or 3) or, preferably, input capture interrupt
// (e.g. pin 8 on Arduino Uno, pin 49 on Mega).  The ESP8266 does not have input capture functionality
// but any pin may be used for level change interrupt.
//
// The bit decoding is done by measuring the time between successive
// interrupts using the 'micros()' function so should be pretty portable.
// Optionally, it will use a faster 16-bit timer for higher resolution.  This is
// the default mode for Uno, Nano and Mega (USETIMER option).
//
// The counter SpareLoopCount is used to see how heavily loaded the processor is.
// With DCC interrupts off, it measures the count.  When the interrupts are attached
// it sees how much the count drops.  The percent load due to the interrupts is
// the percentage difference between the two figures.
// For example (my measurements on an Uno):
//    DCC off, SpareLoopCount=1043042 (over 4 secs)
//    DCC on, SpareLoopCount=768830 (over 4 secs)
//    CPU Load = (1043042-766830)/1043042*100 = 26%
//
// Loco address 3's speed command is optionally mapped onto a PWM output pin, allowing an 
// LED to be used to confirm that a controller is able to send recognisable 
// DCC commands.
//
// When outputting decoded DCC packets, duplicate loco speed packets and idle packets encountered
// within a time period will not be logged (as they are sent continuously).  However, all 
// accessory and loco function packets are displayed, even if repeated.
//
// Set the Serial Monitor Baud Rate to 115200 !!
//
// Keyboard commands that can be sent via Serial Monitor:
// 1 = 1s refresh time
// 2 = 2s 
// 3 = 4s (default)
// 4 = 8s
// 5 = 16s
// 6 = 4 DCC packet buffer
// 7 = 8
// 8 = 16
// 9 = 32 (default)
// 0 = 64
// a = show accessory packets toggle
// l = show locomotive packets toggle
// d = show diagnostics toggle
// h = show heartbeat toggle
// b = show half-bit counts by length toggle
// c = show cpu/irc usage in sniffer toggle
// f = input filter toggle
// s = set NMRA compliance strictness (0=none,1=decoder,2=controller)
// i = Display IP Address
// ? = help (show this information)
//
////////////////////////////////////////////////////////
#include <Arduino.h>

// Configurable parameter items now in separate include file.
#include "Config.h"

////////////////////////////////////////////////////////

#if defined(USE_DIO2) && (defined(ARDUINO_UNO_NANO) || defined(ARDUINO_MEGA))
#define GPIO_PREFER_SPEED
#include <DIO2.h>
#define digitalWrite(pin, state) digitalWrite2(pin, state)
#define digitalRead(pin) digitalRead2(pin)
#endif

#ifdef USETIMER
#include "EventTimer.h"
#else
#include "EventTimer_default.h"
#endif

// Add web server if required.
#if defined(USE_HTTPSERVER)
#include "HttpManager.h"
#endif

// Include OLED if required.
#if defined(USE_OLED)
#include "OledDisplay.h"
#endif

#include "StringBuilder.h"

// Statistics structures and functions.
#include "DCCStatistics.h"

const int nPackets = 16;  // Number of packet buffers
const int pktLength = 8;  // Max length+1 in bytes of DCC packet

// Variables shared by interrupt routine and main loop
volatile byte dccPacket[nPackets][pktLength];  // buffer to hold packets
volatile byte packetsPending = 0;              // Count of unprocessed packets
volatile byte activePacket =
    0;  // indicate which buffer is currently being filled
volatile bool filterInput =
    true;  // conditions input to remove transient changes
volatile byte strictMode =
    1;  // rejects frames containing out-of-spec bit lengths

// Variables used by main loop
byte packetHashListSize = 32;  // DCC packets checksum buffer size
bool showLoc = true;
bool showAcc = true;
bool showHeartBeat = true;
bool showDiagnostics = true;
bool showBitLengths = false;
bool showCpuStats = false;

byte inputPacket = 0;  // Index of next packet to be analysed in dccPacket array
byte pktByteCount = 0;
int packetHashListCounter = 0;
unsigned int packetHashList[64];
bool calibrated = false;
unsigned long lastRefresh = 0;
unsigned int inactivityCount = 0;

// Buffers for decoded packets, used by HTTP and OLED output.
#if defined(USE_HTTPSERVER)
char packetBuffer[5000] = "";
#elif defined(USE_OLED)
char packetBuffer[400] = "";
#else
char packetBuffer[1] = "";
#endif
StringBuilder sbPacketDecode(packetBuffer, sizeof(packetBuffer));

// Pre-declare capture function
bool INTERRUPT_SAFE capture(unsigned long halfBitLengthTicks);

//=======================================================================
// Perform the setup functions for the application.

void setup() {
  Serial.begin(SERIAL_SPEED);
  Serial.println(F("---"));
  Serial.println(F("DCC Packet Analyze initialising"));

#ifdef LEDPIN_ACTIVE
  pinMode(LEDPIN_ACTIVE, OUTPUT);
#endif
#ifdef LEDPIN_DECODING
  pinMode(LEDPIN_DECODING, OUTPUT);
#endif
#ifdef LEDPIN_DECODING
  pinMode(LEDPIN_DECODING, OUTPUT);
#endif
#ifdef LEDPIN_FAULT
  pinMode(LEDPIN_FAULT, OUTPUT);
#endif

  // Enable pullup in case there's no external pullup resistor.
  // External resistor is preferred as it can be lower, so
  // improve the switching speed of the Optocoupler.
  pinMode(INPUTPIN, INPUT_PULLUP);
  Serial.print("INPUTPIN=");
  Serial.println(INPUTPIN);

  if (!EventTimer.inputCaptureMode()) {
    // Output health warning...
    Serial.println(
        F("\r\n** WARNING Measurements will occasionally be out up to ~10us "
          "either way **"));
    Serial.println(
        F("**         because of inaccuracies in the micros() function.        "
          "    **"));
  }

#if defined(USE_OLED)
  // Start OLED display (if required).
  OledDisplay.begin(SDA_OLED, SCL_OLED);
#if defined(ARDUINO_HELTEC_WIFI_KIT_32)
  // Read battery voltage from pin GPIO37
  // The battery measurement is enabled via pin GPIO21
  digitalWrite(21, 0);
  analogSetWidth(12);  // 12 bits = 0-4095
  analogSetPinAttenuation(37, ADC_11db);
  adcAttachPin(37);

  uint32_t batValue = analogRead(37);
  // An input value of around 2600 is obtained for a
  // a measured battery voltage of 4100mV.  
  uint16_t batMV = batValue * 41 / 26;
  if (batMV < 3400) OledDisplay.append("Battery Low");
  digitalWrite(21, 1);  // Disable battery monitor

#endif
  OledDisplay.append("Initialising..");
#endif

// Start WiFi and HTTP server (if required).
#if defined(USE_HTTPSERVER)
  HttpManager.begin(WIFI_SSID, WIFI_PASSWORD, DNSNAME);
#endif

  // Set time for first output of statistics during calibration
  lastRefresh = millis();
  DCCStatistics.setRefreshTime(1);  // Finish calibrating after 1 second

  Serial.print(F("Calibrating... "));
}

//=======================================================================
// Main program loop.

void loop() {
  bool somethingDone = false;

  // The first bit runs one second after setup, and completes the
  // initialisation.
  if (!calibrated && millis() >= lastRefresh + 1000) {
    // Calibration cycle done, record the details.
    Serial.println(F("done."));
    calibrated = true;

    // Read (and discard) stats, then clear them.
    DCCStatistics.getAndClearStats();
    clearHashList();

    // Start recording data from DCC.
    if (!EventTimer.begin(INPUTPIN, capture)) {
      Serial.println(F("Unable to start EventTimer, check configured pin"));
      while (1)
        ;
    }

    DCCStatistics.setRefreshTime(4);
    Serial.print(F("Updates every "));
    Serial.print(DCCStatistics.getRefreshTime());
    Serial.println(F(" seconds"));
    Serial.println(F("---"));

    lastRefresh = millis();

  } else if (millis() >=
             lastRefresh +
                 (unsigned long)DCCStatistics.getRefreshTime() * 1000) {
    // The next part runs once every 'refresh time' seconds.  It primarily
    // captures, resets and
    //  outputs the statistics.

    if (showHeartBeat) Serial.println('-');

    // Snapshot and clear statistics
    Statistics stats = DCCStatistics.getAndClearStats();
    clearHashList();

    // Print DCC Statistics to the serial USB output.
    if (showDiagnostics) {
      DCCStatistics.writeFullStatistics(stats, showCpuStats, showBitLengths);
      Serial.println("--");
    }

// Output short version of DCC statistics to a buffer
// for use by OLED
#if defined(USE_OLED)
    OledDisplay.writeShortStatistics(stats);
    OledDisplay.append(sbPacketDecode.getString());  // Append decoded packets
    // Update OLED
    OledDisplay.refresh();
#endif

// Output full stats for HTTPServer to use
#if defined(USE_HTTPSERVER)
    HttpManager.setBuffer(sbPacketDecode.getString());
    HttpManager.writeHtmlStatistics(stats);
#endif

    sbPacketDecode.reset();  // Empty decoded packet list.

#if defined(ESP32)
    // Check if time to go to sleep on ESP32
    inactivityCount += DCCStatistics.getRefreshTime();
    if (inactivityCount > 120) {
// Go to sleep after 2 minutes of inactivity.
#if defined(USE_OLED)
      OledDisplay.reset();
      OledDisplay.append("Going to sleep..");
#endif
      Serial.println(F("*** Inactivity detected -- going to sleep ***"));
      delay(5000);
#if defined(ARDUINO_HELTEC_WIFI_KIT_32)
      // Turn off WiFi
      WiFi.disconnect(true);
      // Turn off Vext power to screen on Heltec Kit 32 V2
      pinMode(21, OUTPUT);
      digitalWrite(21, 1);
#endif
      esp_deep_sleep_start();
    }
#endif

    lastRefresh = millis();
    somethingDone = true;
  }

  // Check for DCC packets - if found, analyse and display them
  if (processDCC(Serial)) {
    somethingDone = true;
    inactivityCount = 0;
  }

  // Check for commands received over the USB serial connection.
  if (processCommands()) {
    somethingDone = true;
    inactivityCount = 0;
  }

#if defined(USE_OLED)
  OledDisplay.checkButton();
#endif

  // Increment CPU loop counter.  This is done if nothing else was.
  // If the counter never gets incremented, it means that the
  // CPU is fully loaded doing other things and has no spare time.
  if (!somethingDone) DCCStatistics.updateLoopCount();

#if defined(USE_HTTPSERVER)
  HttpManager.process();
#endif

  UpdateLED();
}

//=======================================================================
// Function invoked (from interrupt handler) on change of state of INPUTPIN.
//  It measures the time between successive changes (half-cycle of DCC
//  signal).  Depending on the value, it decodes 0 or a 1 for alternate
//  half-cycles.  A 0 half-bit is nominally 100us per half-cycle (NMRA says
//  90-10000us) and a 1 half-bit is nominally 58us (52-64us).  We treat a
//  half-bit duration < 80us as a '1' half-bit, and a duration >= 80us as a '0'
//  half-bit. Prologue and framing bits are detected and stripped, and data
//  bytes are then stored in the packet queue for processing by the main loop.
//
bool INTERRUPT_SAFE capture(unsigned long halfBitLengthTicks) {
  static byte preambleOneCount = 0;
  static boolean preambleFound = false;
  static int newByte =
      0;  // Accumulator for input bits until complete byte found.
  static int inputBitCount = 0;  // Number of bits read in current newByte.
  static int inputByteNumber =
      0;  // Number of bytes read into active dccPacket buffer so far
  static byte interruptCount = 0;
  static byte previousBitValue = 0, previousDiginState = 0;
  static unsigned int previousHalfBitLengthTicks = 0;
  static byte altbit = 0;  // 0 for first half-bit and 1 for second.
  byte bitValue;

  // The most critical parts are done first - read state of digital input.
  byte diginState = digitalRead(INPUTPIN);

  // Set a high bound on the half bit length
  if (halfBitLengthTicks > 1200 * TICKSPERMICROSEC)
    halfBitLengthTicks = 1200 * TICKSPERMICROSEC;  // microseconds.

  // Calculate time between interrupts in microseconds.
  unsigned int interruptInterval = halfBitLengthTicks / TICKSPERMICROSEC;

  // Precondition input?
  if (filterInput) {
    // Check that the digital input has actually changed since last interrupt,
    // and that the gap between interrupts is realistic.
    if (interruptCount > 0 &&
        (diginState == previousDiginState || interruptInterval <= 3)) {
      // No change in digital, or it was fleeting.  Ignore.
      DCCStatistics.recordGlitch();
      return false;  // reject interrupt
    }
  }

  // If we get here, the interrupt looks valid, i.e. the digital input really
  // did change its state more than 3us after its last change. Calculate
  // difference between current bit half and preceding one, rounding up to next
  // microsecond. This will only be recorded on alternate half-bits, i.e. where
  // the previous and current half-bit make a complete bit.
  long deltaTicks = halfBitLengthTicks - previousHalfBitLengthTicks;
  if (deltaTicks < 0) deltaTicks = -deltaTicks;
  unsigned int delta = (deltaTicks + TICKSPERMICROSEC - 1) / TICKSPERMICROSEC;

  // Check length of half-bit
  if (interruptInterval < 80)
    bitValue = 1;
  else
    bitValue = 0;

  // Record input state and timer values ready for next interrupt
  previousDiginState = diginState;
  previousHalfBitLengthTicks = halfBitLengthTicks;

  // If first or second interrupt, then exit as the previous state is
  // incomplete.
  if (interruptCount < 2) {
    interruptCount++;
    previousBitValue = bitValue;
    return true;
  }

#ifdef LEDPIN_ACTIVE
  digitalWrite(LEDPIN_ACTIVE, 1);
#endif

  // Check if we're on the first or second half of the bit.
  if (bitValue != previousBitValue) {
    // First half of new bit received
    altbit = false;
  } else {
    // Toggle for alternate half-bits
    altbit = !altbit;
  }
  previousBitValue = bitValue;

  // Update statistics
  DCCStatistics.recordHalfBit(altbit, bitValue, interruptInterval, delta);

  // Store interrupt interval for use on next interrupt.
  previousHalfBitLengthTicks = halfBitLengthTicks;

  // If this is the second half-bit then we've got a whole bit!!
  if (altbit) {
    bool rejectBit = false;
    if (strictMode == 2) {
      // Validate bit lengths against NMRA spec for controllers
      if (bitValue == 0) {
        if (interruptInterval < 95 || interruptInterval > 9900) {
          rejectBit = true;
        }
      } else {
        if (interruptInterval < 55 || interruptInterval > 61 || delta > 3) {
          rejectBit = true;
        }
      }
    } else if (strictMode == 1) {
      // Validate bit lengths against NMRA spec for decoders.
      if (bitValue == 0) {
        if (interruptInterval < 90 || interruptInterval > 10000) {
          rejectBit = true;
        }
      } else {
        if (interruptInterval < 52 || interruptInterval > 64 || delta > 6) {
          rejectBit = true;
        }
      }
    }
    // Record error only if we're in a packet (preamble has been read).
    if (rejectBit && preambleFound) {
      DCCStatistics.recordOutOfSpecRejection();
      // Search for next packet
      preambleFound = 0;
      preambleOneCount = 0;
    }

    // Now we've got a bit, process it.  The message comprises the following:
    //   Preamble: 10 or more '1' bits followed by a '0' start bit.
    //   Groups of 9 bits each containing data byte of 8 bits, followed by a
    //   '0' bit (if message not yet finished), or a '1' bit (if the byte is
    //   the last byte of the message, i.e. the checksum).
    //
    if (!preambleFound) {
      if (bitValue == 1) {
        // Reading preamble perhaps...
        preambleOneCount++;
      } else if (preambleOneCount < 10) {  // and bitValue==0)
        // Preamble not yet found, but zero bit encountered.  Restart preable
        // count.
        preambleOneCount = 0;
      } else {  // preambleOneCount >= 10 and bitValue==0
        // Start bit found at end of preamble, so prepare to process data.
        preambleFound = true;
        newByte = 0;
        inputBitCount = 0;
        inputByteNumber = 0;
      }
    } else {  // Preamble previously found, so this is a message bit
      if (packetsPending == nPackets) {
        // Previous DCC packets haven't been processed by the main loop,
        // so there is no buffer for the incoming message.
        // Discard incoming message and scan for another preamble.
        preambleFound = false;
        preambleOneCount = 0;

        // Record this event in a counter.
        DCCStatistics.recordLostPacket();

      } else {
        // Preamble read, packet buffer available, so message bit can be stored!
        if (inputBitCount == 8) {  // Byte previously completed, so this bit is
                                   // the interbyte marker
          if (bitValue == 0) {  // Interbyte marker is zero, so prepare for next
                                // byte of data
            inputBitCount = 0;
          } else {  // one-bit found, marks end of packet
            // End of packet found
            dccPacket[activePacket][0] =
                inputByteNumber;  // save number of bytes
            packetsPending++;     // flag that packet is ready for processing
            if (++activePacket >= nPackets)
              activePacket = 0;     // move to next packet buffer
            preambleFound = false;  // scan for another preamble
            preambleOneCount =
                1;  // allow the current bit to be counted in the preamble.
          }
        } else {  // Reading packet data at this point.
          // Append received bit to the current new byte.
          newByte = (newByte << 1) | bitValue;
          if (++inputBitCount == 8) {  // Completed byte, save byte (if room)
            if (inputByteNumber < pktLength - 1)
              dccPacket[activePacket][++inputByteNumber] = newByte;
            else {  // packet has filled buffer so no more bits can be stored!
              packetsPending++;  // flag that packet is ready for processing
              if (++activePacket >= nPackets)
                activePacket = 0;     // move to next packet buffer
              preambleFound = false;  // scan for another preamble
              preambleOneCount = 0;
              // Record this event in a counter.
              DCCStatistics.recordLongPacket();
            }
            newByte = 0;
          }
        }
      }
    }
  }

#ifdef LEDPIN_ACTIVE
  // Turn out ACTIVE LED.
  digitalWrite(LEDPIN_ACTIVE, 0);
#endif

  // Calculate time taken in interrupt code between the measured time of event
  // to POINTB.

  unsigned int interruptDuration =
      EventTimer.elapsedTicksSinceLastEvent() / TICKSPERMICROSEC;  // POINTB

  // Assume that there are about 25 cycles of instructions in this function that
  // are not measured, and that the prologue in dispatching the function (saving
  // registers etc) is around 51 cycles and the epilogue (restoring registers
  // etc) is around 35 cycles.  This adds a further (51+25+35)/16MHz=6.9us to
  // the calculation. See
  // https://billgrundmann.wordpress.com/2009/03/02/the-overhead-of-arduino-interrupts/.
  // However, if the Input Capture mode is used, then this will be much smaller.
  // So ignore it.
  // interruptDuration += 7;

  // Record result
  DCCStatistics.recordInterruptHandlerTime(interruptDuration);

  return true;  // Accept interrupt.
}
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

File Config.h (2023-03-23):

/* Copyright (c) 2021 Neil McKechnie
 *
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
 * You should have received a copy of the GNU General Public License
 * along with this software.  If not, see
 * <http://www.gnu.org/licenses/>.
 */

#ifndef config_h
#define config_h

// The following logic should work for all supported platforms, hopefully.
#if defined(ARDUINO_heltec_wifi_kit_32) || defined(ARDUINO_WIFI_KIT_32)
#define ARDUINO_HELTEC_WIFI_KIT_32
#endif

#if defined(ESP_PLATFORM)
  #if !defined(ESP32)
    #define ESP32
  #endif
#elif defined(ESP8266)
  // nothing needs done here.
#elif defined(ARDUINO_AVR_UNO) || defined(ARDUINO_AVR_NANO)
  #define ARDUINO_UNO_NANO
#elif defined(ARDUINO_AVR_MEGA2560)
  #define ARDUINO_MEGA
#else
  #error "Platform not recognised"
#endif

// Uncomment the "#define USE_DIO2" to use the 'Fast digital i/o library' DIO2
// in place of the normal digitalRead() and digitalWrite().
// Reduces CPU load by about 17%.  Only applicable to Arduino Uno/Mega/Nano.
#define USE_DIO2

// Uncomment the "#define USETIMER" to perform the timing using the ATmega328's 
// and ESP32's Input Capture mode which captures the time through hardware instead
// of software.  This enables a higher accuracy and consistency, and because we can capture the 
// Timer counter register (TCNTn) at the time of the digital change, it is immune to 
// timing errors caused by other interrupts.
// Works on Arduino Uno (Timer1/pin D8)
//          Arduino Nano (Timer1/pin D8)
//          Arduino Mega (Timer4/pin D49)
// If we don't use this, then the selected input pin must support change interrupt 
// (defaults to pin D2 on Uno, Nano and Mega, GPIO2 on ESP8266 and GPIO5 on ESP32.
#define USETIMER 

// Input pin definitions.  Defaults:
//    Nano (USETIMER):               8
//    Uno (USETIMER):                8
//    Mega (USETIMER):               49
//    Nano/Uno/Mega, Non-USETIMER:   2
//    ESP32:                         5
//    ESP8266:                       2
//    Other:                         2
#if defined(USETIMER)
  #if defined(ARDUINO_UNO_NANO)
    #define INPUTPIN 8
  #elif defined(ARDUINO_MEGA)
    #define INPUTPIN 49
  #elif defined(ESP32)
    #define INPUTPIN 5
  #else
    // Assume timer not supported, use default pin
    #undef USETIMER
    #define INPUTPIN 2
  #endif
#else
  #if defined(ESP32) 
    #define INPUTPIN 5
  #else
    #define INPUTPIN 2
  #endif
#endif

// Uncomment following lines to enable OLED output on pins SDA_OLED and SCL_OLED.
//  (ESP or Mega only).
#define USE_OLED        

#if defined(ESP8266) // Heltec Kit 8 has pins 4/15 for I2C.
  #define SDA_OLED 4   
  #define SCL_OLED 5
  #define OLED_RESET 16
  #define OLED_I2CADDRESS 0x3C
  #define SCREEN_WIDTH 128
  #define SCREEN_HEIGHT 32
#elif defined(ARDUINO_HELTEC_WIFI_KIT_32)    // Heltec Kit 32 has pins 4/15 predefined for I2C.
  // #define SDA_OLED 4
  // #define SCL_OLED 15
  #define OLED_RESET 16
  #define OLED_I2CADDRESS 0x3C
  #define SCREEN_WIDTH 128
  #define SCREEN_HEIGHT 64
#else                   // Other boards - edit as appropriate.
  #define SDA_OLED 4
  #define SCL_OLED 5
  #define OLED_RESET 16
  #define OLED_I2CADDRESS 0x3D
  #define SCREEN_WIDTH 128
  #define SCREEN_HEIGHT 64
#endif
// Button for selecting new page on OLED.  The button action is carried out
// when the pin goes from 1 to 0 (pull-up is enabled).
#define BUTTONPIN 0

// LED pin definitions - uncomment and assign as required.
//#define LEDPIN_ACTIVE 13    // Shows interrupts being received, ie DCC active
//#define LEDPIN_LOCOSPEED 3  // Driven from loco speed packet for loco 3
//#define LEDPIN_DECODING 7   // lights when a packet with valid checksum is received
//#define LEDPIN_FAULT 6      // Lights when a checksum error or glitch is encountered.

// Uncomment the following line to enable HTTP Server (ESP32 or ESP8266 only).
#define USE_HTTPSERVER

// SSID and password can be configured here.  However, the server will, by preference,
// connect using the same credentials as last time; if that fails it will try WPS; 
// only if that fails too, will it use the credentials below.
#define WIFI_SSID ""
#define WIFI_PASSWORD ""

// Name used by mDNS to register the device.  On some browsers it can be accessed
// through this name with a ".local" suffix (e.g. http://DccInspector.local/).
#define DNSNAME "DccInspector"

// OLED isn't supported on Uno or Nano
#if defined(ARDUINO_UNO_NANO)
  #if defined(USE_OLED)
    #undef USE_OLED
  #endif
#endif

// HTTP Server isn't supported on Uno or Nano or Mega
#if defined(ARDUINO_UNO_NANO) | defined(ARDUINO_MEGA)
  #if defined(USE_HTTPSERVER)
    #undef USE_HTTPSERVER
  #endif
#endif

#define SERIAL_SPEED 115200

#if defined(ESP32) || defined(ESP8266) || defined(ESP_PLATFORM)
  #define INTERRUPT_SAFE IRAM_ATTR
#else
  #define INTERRUPT_SAFE
#endif

#endif

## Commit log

2021-01-27 Major enhancements
    Webserver, ESP32 input capture and OLED support.
2021-01-27 Fix L and A commands.
    Correct handling of L and A commands.
    [DCCInspector-EX.ino]
2021-02-10 Update readme opto circuit.
2021-04-18 Add buttons to web page for options
    Add configuration buttons to the web page.
    Tidy up structure a little.
    Fix a couple of bugs.
    [DCCInspector-EX.ino, DCCStatistics.cpp, HttpManager.cpp]
2021-04-19 Update DCCInspector-EX.ino
    Fix calculation of parameter in Binary State Control Instruction Long form.
    [DCCInspector-EX.ino]
2021-04-27 Bug fix on calculation of binary state control instruction long form (Functions >=128).
    [DCCInspector-EX.ino]
2021-06-22 Issue #7 - change to decoded output (#8)
    For 28-step decoded packets, Forw replaced with Fwd28 and Rev replaced with Rev28 (for consistency with Fwd128 and Rev128 messages).
    [DCCInspector-EX.ino]
2021-07-08 Correct capitalisation of .h file names.
    Fix compile error on Unix platform due to mismatch in capitalisation of file names.
    [DCCInspector-EX.ino, HttpManager.cpp]
2021-07-08 Correct capitalisation of .h file names.
    [DCCInspector-EX.ino, EventTimer_AtMega.h]
2023-02-24 First commit of hardware folder
    [oled_inspector.kicad_pcb, oled_inspector.kicad_sch, optoiso-board-only.kicad_pcb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]
2023-02-24 Add stand-alone optoisolator board project to EX-DCCInspector
    [optoiso-board-only.kicad_sch]
2023-03-23 Bugfixes (#15)
    * Add Heltec module support
    * Fix issue #14 HW Capture not working on Mega
    * Fix issue #12 Compile errors
    Update code to work with ESP32 support v2.0.4 (current on Arduino and on PlatformIO).
    * Get rid of 'undefined LED_BUILTIN' errors.
    * Fix compilation errors on Heltek Dev Kit 32
    * Add yet another Heltec board category
    * Update .gitignore
    * Remove excluded files
    [Config.h, DCCInspector-EX.ino, EventTimer_ESP32.h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]
2025-04-28 Detect RCN 5mS errors
    [DCCInspector-EX.ino, DCCStatistics.cpp, HttpManager.cpp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]

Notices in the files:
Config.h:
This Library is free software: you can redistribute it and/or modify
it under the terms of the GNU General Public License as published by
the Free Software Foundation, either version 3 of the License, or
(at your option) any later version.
